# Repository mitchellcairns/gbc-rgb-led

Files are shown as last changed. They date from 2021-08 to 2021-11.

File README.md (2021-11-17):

# gbc-rgb-led 
**DEPRECIATED - SEE https://github.com/mitchellcairns/gbc-rgb-led-2.0**

__________________________
Gameboy Color RGB board for lighting up buttons with on-board controls.

This mod has the following modes and features
- Rainbow fade mode
- User preset mode to change hue and saturation of each button individually
- LEDs for all buttons and the power LED
- Brightness control
- All settings save to EEPROM so your preference is remembered through power cycles/battery changes

Controls in idle mode
- Press select three times and hold on the final press = Enter config mode
- While in config mode, use dpad left and right to change color mode
- After selecting your color mode, press select three times and hold on final press = Enter color edit mode

If you are in 'User preset mode'
- Use dpad left and right to select which LED you'd like to modify
- press select twice and hold to enter hue selection mode
- use dpad left and right to select your hue
- press twice and hold to enter saturation selection mode
- use dpad left and right to select your saturation
- press select twice and hold to go back to button selection
- press select three times and hold to enter brightness selection mode

If you are in 'Rainbow color mode'
- Use dpad left and right to change the rainbow fade speed
- press three times and hold to enter brightness selection mode

If you are in 'Solid color mode'
- Use dpad left and right to change the color hue
- press select twice and hold to enter saturation selection mode
- use dpad left and right to select your saturation
- press select three times and hold to enter brightness selection mode

If you are in 'Brightness selection mode'
- Use dpad left and right to choose your brightness
- press select three times and hold to save all settings and return to 'Idle' mode

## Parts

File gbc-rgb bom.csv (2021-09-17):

Item Link | Qty | Item Name | Board Label
https://www.aliexpress.com/item/32878302621.html?spm=a2g0s.9042311.0.0.12ab4c4d19utiV | 9 | WS2812B-2020 (5mA variant) | L1-L9
https://www.aliexpress.com/item/1005003126067624.html | 1 | ATTINY85-20SU SOP-8 | U1
https://www.aliexpress.com/item/1005001436923851.html | 1 | 330 ohm 0603 SMT resistor | R1
https://www.digikey.com/en/products/detail/yageo/RE0603FRE071KL/5923313 | 1 | 1k ohm 0603 SMT resistor | R2

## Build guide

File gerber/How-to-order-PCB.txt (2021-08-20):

How to Order PCB

Please refer to:
https://docs.easyeda.com/en/PCB/Order-PCB

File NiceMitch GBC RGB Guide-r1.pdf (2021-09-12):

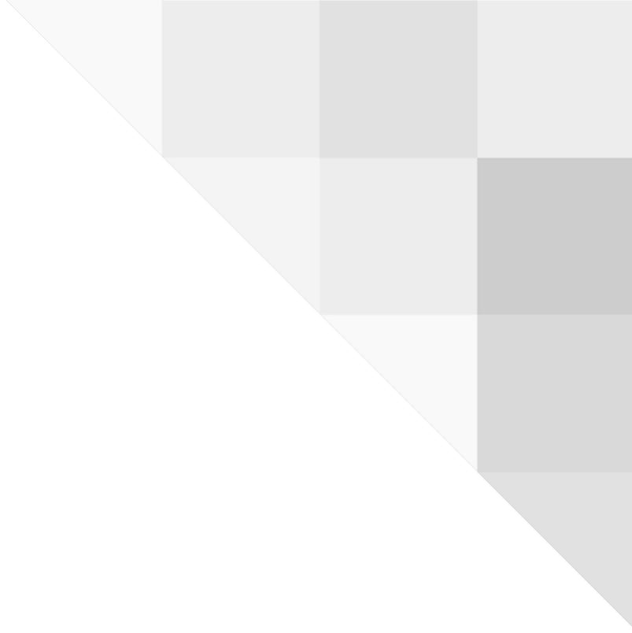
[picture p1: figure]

# NiceMitch’s GBC RGB Guide

# Product Guide

Last Updated September 12th, 2021

# 1. Product Controls Overview

There are two types of inputs-- presses and holds.

A press is performed by pressing the Select button, or D-Pad Left or Right.

A hold is performed by pressing the Select button any number of times, then holding the final press. Keep these directions in mind when reading the guide below and you will be successful in configuring/controlling your LEDs.

# 2. Color Modes

### A. Preset mode -- Modifiable color preset B. Solid color mode -- A mode to simply display one color C. Rainbow fade mode -- A mode that fades between all colors continuously

# 3. Device Modes and Controls

## A. Default mode

Upon receiving your kit, the device will be in ‘default’ mode. You can enter configuration mode by pressing select 3 times and holding. You will know you’ve entered configuration mode when you see the lights flash teal twice.

## B. Configuration mode

When you enter configuration mode, you will first enter the color mode select phase. Press Dpad Left and Right to cycle between each of the 3 color modes.

In advanced configuration mode, press select three times and hold to enter edit mode; this is the second step which will allow you to customize your chosen color mode. You will know you are entering edit mode when you see the lights flash pink twice.

## C. Edit mode

Edit mode will change depending on the color mode you are in.

1. When in preset mode:
a. Dpad left and right are pressed to select which button you would like to modify.
b. Press select twice and hold to enter hue selection for the chosen button. Dpad left and right can be used to adjust the color hue.
c. Press select twice and hold again to enter saturation selection for the chosen button. Dpad left and right can be used to adjust the color saturation.
d. Press select twice and hold again to go back to button selection.
2. When in solid color mode:
a. Hue selection mode is the default. Press select twice and hold to enter saturation selection mode. Use the dpad to change the hue.
b. Press select twice and hold to go back to hue selection mode. Use the dpad to change saturations.
3. When in rainbow mode:
a. Dpad left and right adjusts the color fade speed.
4. To save and continue to brightness configuration mode, press select three times and hold. You will know you’ve entered brightness mode when the leds flash yellow twice.

## D. Brightness configuration mode

This mode simply lets you change the brightness. This is the final setting that needs to be modified before all settings can be saved to the onboard storage.

1. Adjust brightness with dpad left and right.
2. Save all settings and reboot -- press select three times and hold. You will know you have saved all settings when you see the lights flash white twice.

# 4. Flex PCB Install

a. Disassemble your Gameboy Color console. See this guide on iFixit (https://www.ifixit.com/Teardown/Game+Boy+Color+Teardown/73017) for details.
b. Remove the power LED by heating the two legs from the rear side of the board with a soldering iron. Adding fresh solder to these two points can help. Solder wick or a solder sucker can help.

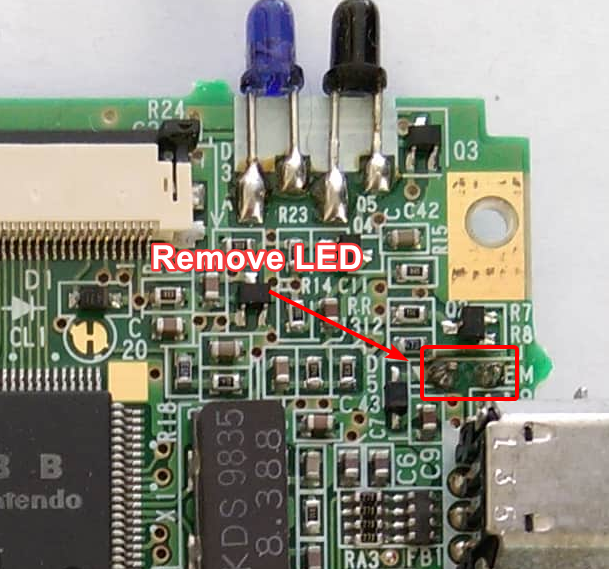
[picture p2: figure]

c. Flip the Gameboy Color PCB over. Align the flex board on the main board as shown. You will solder each of the points circled in red. Be sure to check your

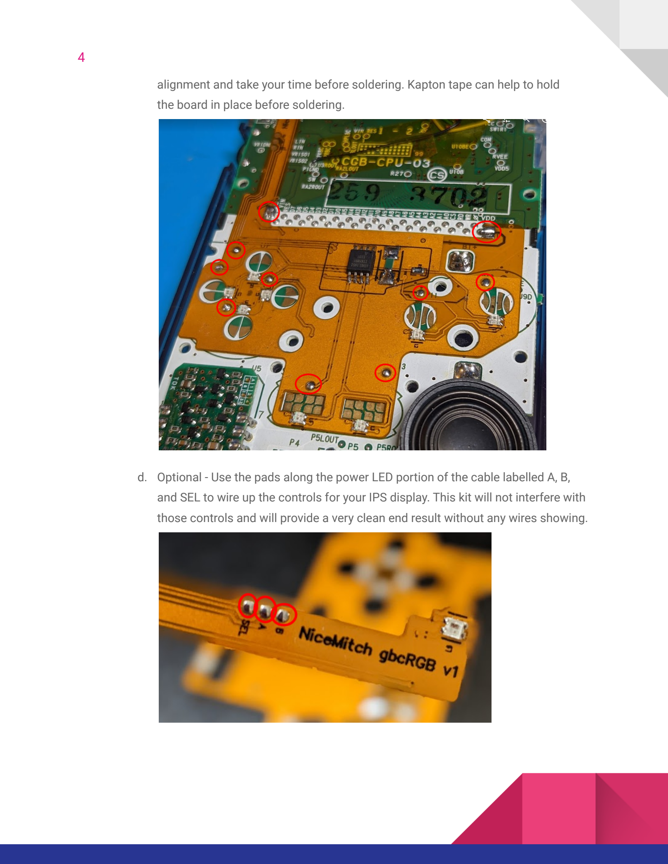
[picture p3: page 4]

alignment and take your time before soldering. Kapton tape can help to hold the board in place before soldering.

d. Optional - Use the pads along the power LED portion of the cable labelled A, B, and SEL to wire up the controls for your IPS display. This kit will not interfere with those controls and will provide a very clean end result without any wires showing.

e. Once you have ensured all connections are secured, you can reassemble and test. The lights should turn on immediately when powering up. An additional strip of kapton tape can be used to secure the long portion of the flex cable with the power LED. If you do have any issues, feel free to join my discord channel for additional support: https://discord.gg/jFxtr9mzCB

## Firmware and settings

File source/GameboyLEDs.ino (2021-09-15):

#include <FastLED.h>
#include <EEPROM.h>
#include "config.h"

#define LED_PIN 4

#define LED_COUNT 9

#define CHECK_COUNT 8 // How many times to poll buttons for averages
#define CHECK_SAVE 8

#define MAX_BRIGHTNESS 80
#define RCV 180

// PIN setup
// ----------------
const int selPIN = 0;
const int leftPIN = 2;
const int rightPIN = 1;
// ----------------
// ----------------

// Button states setup
#define NO_PRESS        0
#define RELEASED_PRESS  1
#define HELD_PRESS      2
// ----------------
// ----------------

// Dpad states setup
#define DPAD_LEFT       0
#define DPAD_RIGHT      1
#define DPAD_NEUTRAL    2
byte dpadPresses = 0;

// Release state setup
#define HELD_START      100
#define HELD_ONE        100
#define HELD_TWO        101
#define HELD_THREE      102
// ----------------
// ----------------

// Definitions for the different color modes
byte colorMode = 0;
#define COLORMODE_RAINBOW 0
#define COLORMODE_USER 1
#define COLORMODE_SOLID 2
// ----------------
// ----------------

int brightness = 20;

int selValue = HIGH;
int leftValue = HIGH;
int rightValue = HIGH;

bool leftPressed = false;
bool rightPressed = false;
byte selPressed = 0;
bool finishedHold = true;

byte timer = 0;
byte buttonTime = 250;
byte buttonPresses = 0;


bool colorDirty = true;
bool colorSet = false; // Set true to start a fade
bool colorInit = false; // Set true after changing and setting up your mode
float colorIncrement = 0; // Used to determine how to fade

byte colorStep = 15;
byte fadeTime = 50;
byte rainbowTime = 50;
#define COLOR_TIME    50
CHSV rainbowColor = CHSV(0,255,RCV);

CRGB leds[LED_COUNT] = { CRGB::Black, CRGB::Black, CRGB::Black, CRGB::Black, CRGB::Black, CRGB::Black, CRGB::Black, CRGB::Black, CRGB::Black};;
CRGB lastLeds[LED_COUNT];
CRGB nextLeds[LED_COUNT];
CRGB ledPreset[LED_COUNT] = { 0xff0505, 0xff8605, 0xfff700, 0x22ff00, 0x0022ff, 0x0022ff, 0x0022ff, 0x0022ff, 0xAE00ff};
CRGB editPresetLeds[LED_COUNT];

UserPreference upref;

void setup() {
  
  // put your setup code here, to run once:
  FastLED.addLeds<WS2812B, LED_PIN, RGB>(leds, LED_COUNT);
  FastLED.setBrightness(brightness);
  rainbowColor.value = RCV;

  pinMode(selPIN, INPUT_PULLUP);
  pinMode(leftPIN, INPUT_PULLUP);
  pinMode(rightPIN, INPUT_PULLUP);
  pinMode(3, OUTPUT);
  digitalWrite(3, LOW);

  delay(100);
  EEPROM.get(0, upref);
  delay(100);

  // Try to load upref data
  if (upref.saved == CHECK_SAVE) {
    brightness = upref.brightness;
    colorMode = upref.colorMode;
    rainbowTime = upref.rainbowTime;
    rainbowColor.hue = upref.hue;
    rainbowColor.saturation = upref.saturation;
    for (byte i = 0; i < LED_COUNT; i++) {
      ledPreset[i] = upref.ledPreset[i];
    }
  }

  FastLED.show();
  
}

void loop() {
  byte butt = buttonCounter();
  idle(butt);
}

// Functions to handle looking at the different button inputs

void smooth() { // Smooth read of values
  selValue = HIGH;
  rightValue = HIGH;
  leftValue = HIGH;

  for (byte i = 0; i < CHECK_COUNT; i++) {
    if (digitalRead(selPIN) == LOW) selValue = LOW;
    if (digitalRead(rightPIN) == LOW) rightValue = LOW;
    if (digitalRead(leftPIN) == LOW) leftValue = LOW;
  }
  FastLED.delay(1);

}

byte buttonCheck(bool timeOver) {
  smooth();

  dpadPresses = dpadCheck();

  if (selValue==LOW and !selPressed) {
    selPressed = true;
  }
  else if (selPressed and selValue==HIGH and finishedHold) {
    selPressed = false;
    return RELEASED_PRESS;
  }
  else if (!finishedHold and selValue==HIGH){
    selPressed = false;
    finishedHold = true;
  }
  
  if (selPressed and timeOver) {
    selPressed = false;
    finishedHold = false;
    return HELD_PRESS;
  }

  return NO_PRESS;
}

byte dpadCheck()  {
  
  if (!leftPressed and leftValue==LOW) {
    leftPressed = true;
  }
  else if (leftPressed and leftValue==HIGH) {
    leftPressed = false;
    return DPAD_LEFT;
  }

  if (!rightPressed and rightValue==LOW) {
    rightPressed = true;
  }
  else if (rightPressed and rightValue==HIGH) {
    rightPressed = false;
    return DPAD_RIGHT;
  }
  return DPAD_NEUTRAL; 
}

byte buttonCounter() {
  if (timer > 0 and timer < buttonTime) { // If we're in a time loop, do the following
    timer += 1;
  }

  byte btChk = 0;
  if (timer >= buttonTime) btChk = buttonCheck(true);
  else btChk = buttonCheck(false);
  
  if (btChk == RELEASED_PRESS) { // When a button is pressed what do we do?
    if (timer == 0 and buttonPresses == 0) { // If we haven't started a timer, lets add a button press and begin adding to the timer.
      timer += 1;
      buttonPresses = 1;
    }
    else if (timer < buttonTime) { // If we are still in the allotted timeframe, add another button press.
      buttonPresses += 1;
    }
  }
  
  if (timer >= buttonTime) { // What do we do if the timer is full? We reset the timer, return the button press count and reset that.
    byte toReturn = buttonPresses;
    if (btChk == HELD_PRESS){
      toReturn += HELD_START;
    }
    buttonPresses = 0;
    timer = 0;
    return toReturn;
  }

  // Default return 0
  return 0;
}
// ----------------
// ----------------

// Definitions for device modes
byte configMode = 0;
#define DEFAULT_MODE      0
#define CONFIG_MODE       1
#define EDIT_MODE         2
#define BRIGHTNESS_MODE   3
// ----------------
// ----------------

// Definitions for dit modes
byte editMode = 0;
#define EDIT_CHOOSE       0
#define EDIT_HUE          1
#define EDIT_SATURATION   2

byte presetEdit = false;

// Definitions for different button functions
#define SATURATION_UP     0 //
#define SATURATION_DOWN   1 //
#define HUE_UP            2 //
#define HUE_DOWN          3 //
#define COLOR_MODE_UP     4 //
#define COLOR_MODE_DWN    5 //
#define RAINBOW_UP        6 //
#define RAINBOW_DOWN      7 //
#define BRIGHT_UP         8 //
#define BRIGHT_DOWN       9 //
#define SAVE_ALL          10
#define ENABLE_CONFIG     11 
#define NEXT_BUTTON       12
#define PREV_BUTTON       13
#define ENABLE_EDIT       14
#define ENABLE_BRIGHTNESS 15
#define RESET_CALIBRATION 16
#define ENABLE_HUESELECT  17
#define ENABLE_SATSELECT  18

// ----------------
// ----------------

// Definitions for modifying user preset
byte buttonEditing = 0;
#define A_EDIT            0
#define B_EDIT            1
#define DPAD_EDIT         2
#define SEL_EDIT          3
#define START_EDIT        4
#define POWER_EDIT        5

void buttonFunction(byte in)  {
  if (in == COLOR_MODE_UP) {
    if (colorMode + 1 > 2) colorMode = 0;
    else colorMode += 1;
    if (colorMode == COLORMODE_SOLID)
    {
      if (upref.saved == CHECK_SAVE) {
        rainbowColor.hue = upref.hue;
        rainbowColor.saturation = upref.saturation;
      }
      else rainbowColor = CHSV(0,255,RCV);
    }
    resetColor(false);
  }
  else if (in == COLOR_MODE_DWN) {
    if (colorMode - 1 < 0) colorMode = 2;
    else colorMode -= 1;
    if (colorMode == COLORMODE_SOLID)
    {
      if (upref.saved == CHECK_SAVE) {
        rainbowColor.hue = upref.hue;
        rainbowColor.saturation = upref.saturation;
      }
      else rainbowColor = CHSV(0,255,RCV);
    }
    resetColor(false);
  }
  else if (in == SATURATION_UP) {
    if (rainbowColor.saturation + 20 >= 255)
    rainbowColor.saturation = 255;
    else rainbowColor.saturation += 20;
    if (configMode == EDIT_MODE and colorMode == COLORMODE_USER)
      setButtonGroup(buttonEditing, false);
    resetColor(colorMode == COLORMODE_RAINBOW);
  }
  else if (in == SATURATION_DOWN) {
    if (rainbowColor.saturation - 20 <= 0)
    rainbowColor.saturation = 0;
    else rainbowColor.saturation -= 20;
    if (configMode == EDIT_MODE and colorMode == COLORMODE_USER)
      setButtonGroup(buttonEditing, false);
    resetColor(colorMode == COLORMODE_RAINBOW);
  }
  else if (in == BRIGHT_UP) {
    if (brightness + 10 >= MAX_BRIGHTNESS)
    brightness = MAX_BRIGHTNESS;
    else brightness += 10;
    FastLED.setBrightness(brightness);
    FastLED.show();
  }
  else if (in == BRIGHT_DOWN) {
    if (brightness - 10 <= 0)
    brightness = 0;
    else brightness -= 10;
    FastLED.setBrightness(brightness);
    FastLED.show();
  }
  else if (in == NEXT_BUTTON) {
    if (buttonEditing + 1 > 5) buttonEditing = 0;
    else buttonEditing += 1;
    rainbowColor = CHSV(0,255,RCV);
    setButtonGroup(buttonEditing, true);
  }
  else if (in == PREV_BUTTON) {
    if (buttonEditing - 1 < 0) buttonEditing = 5;
    else buttonEditing -= 1; 
    rainbowColor = CHSV(0,255,RCV);
    setButtonGroup(buttonEditing, true);
  }
  else if (in == HUE_UP) {
    rainbowColor.hue += 15;
    if (rainbowColor.hue > 255) rainbowColor.hue = 0;
    if (configMode == EDIT_MODE and colorMode == COLORMODE_USER)
      setButtonGroup(buttonEditing, false);
    resetColor(colorMode == COLORMODE_RAINBOW);
  }
  else if (in == HUE_DOWN) {
    rainbowColor.hue -= 15;
    if (rainbowColor.hue < 0) rainbowColor.hue = 255;
    if (configMode == EDIT_MODE and colorMode == COLORMODE_USER)
      setButtonGroup(buttonEditing, false);
    resetColor(colorMode == COLORMODE_RAINBOW);
  }
  else if (in == RAINBOW_UP) {
    rainbowTime += 10;
    if (rainbowTime > 60) rainbowTime = 60;
  }
  else if (in == RAINBOW_DOWN) {
    rainbowTime -= 10;
    if (rainbowTime <= 10) rainbowTime = 10;
  }
  else if (in == ENABLE_CONFIG) {
    configMode = CONFIG_MODE;
    switchIndicator(CRGB::Teal);
    resetColor(false);
  }
  else if (in == ENABLE_EDIT) {
    configMode = EDIT_MODE;
    if (colorMode == COLORMODE_USER) {
      rainbowColor = CHSV(0,255,RCV); // Set to red
      editMode = EDIT_CHOOSE;
      setButtonGroup(buttonEditing, true);
    }
    else if (colorMode == COLORMODE_SOLID) {
      editMode = EDIT_HUE;
    }
    switchIndicator(CRGB::Pink);
    resetColor(false);
  }
  else if (in == ENABLE_BRIGHTNESS) {
    configMode = BRIGHTNESS_MODE;
    switchIndicator(CRGB::Yellow);
    resetColor(false);
  }
  else if (in == ENABLE_HUESELECT) {
    editMode = EDIT_HUE;
    if (colorMode == COLORMODE_USER)
    {
      setButtonGroup(buttonEditing, false);
    }
    switchIndicator(CRGB::Pink);
    resetColor(false);
  }
  else if (in == ENABLE_SATSELECT) {
    editMode = EDIT_SATURATION;
    if (colorMode == COLORMODE_USER)
    {
      setButtonGroup(buttonEditing, false);
    }
    switchIndicator(CRGB::Red);
    resetColor(false);
  }
  else if (in == SAVE_ALL)  {
    upref.saved = CHECK_SAVE;
    upref.brightness = brightness;
    upref.colorMode = colorMode;
    upref.rainbowTime = rainbowTime;
    upref.hue = rainbowColor.hue;
    upref.saturation = rainbowColor.saturation;
    for (byte i = 0; i < LED_COUNT; i++) {
      upref.ledPreset[i] = ledPreset[i];
    }
    
    EEPROM.put(0, upref);
    delay(100);
    configMode = DEFAULT_MODE;
    switchIndicator(CRGB::White);
    resetColor(false);
  }

}

void switchIndicator(CRGB col) {
  FastLED.setBrightness(25);
  for (byte i = 0; i < 2; i++)
  {
    fill_solid(leds, LED_COUNT, col);
    FastLED.show();
    delay(500);
    FastLED.clear();
    FastLED.show();
    delay(500);
  }
  FastLED.setBrightness(brightness);
}

void setNextColors(CRGB colors[LED_COUNT]) {
  for (byte i = 0; i < LED_COUNT; i++) {
    lastLeds[i] = leds[i];
    nextLeds[i] = colors[i];
  }
  resetColor(false);
}

void setNextColor(CRGB color) {
  for (byte i = 0; i < LED_COUNT; i++) {
    lastLeds[i] = leds[i];
    nextLeds[i] = color;
  }
  resetColor(colorMode==COLORMODE_RAINBOW);
}

// Button groups
// 0,1 are A button
// 2 are B button
// 3 reserved for Power indicator for debug

void setButtonGroup(byte buttonGroup, bool loadDefault) {
    
  for (byte i = 0; i < LED_COUNT; i++) {
    editPresetLeds[i] = CHSV(0,25,25);
  }
  
  if (buttonGroup == A_EDIT) {
    if (loadDefault) {
      editPresetLeds[0] = ledPreset[0];
    }
    else {
      editPresetLeds[0] = rainbowColor;
      ledPreset[0] = rainbowColor;
    }
  }
  else if (buttonGroup == B_EDIT) {
    if (loadDefault) {
      editPresetLeds[1] = ledPreset[1];
    }
    else {
      editPresetLeds[1] = rainbowColor;
      ledPreset[1] = rainbowColor;
    }
  }
  else if (buttonGroup == DPAD_EDIT) {
    if (loadDefault) {
      editPresetLeds[4] = ledPreset[4];
      editPresetLeds[5] = ledPreset[5];
      editPresetLeds[6] = ledPreset[6];
      editPresetLeds[7] = ledPreset[7];
    }
    else {
      editPresetLeds[4] = rainbowColor;
      ledPreset[4] = rainbowColor;
      editPresetLeds[5] = rainbowColor;
      ledPreset[5] = rainbowColor;
      editPresetLeds[6] = rainbowColor;
      ledPreset[6] = rainbowColor;
      editPresetLeds[7] = rainbowColor;
      ledPreset[7] = rainbowColor;
    }
  }
  else if (buttonGroup == START_EDIT) {
    if (loadDefault) {
      editPresetLeds[2] = ledPreset[2];
    }
    else {
      editPresetLeds[2] = rainbowColor;
      ledPreset[2] = rainbowColor;
    }
  }
  else if (buttonGroup == SEL_EDIT) {
    if (loadDefault) {
      editPresetLeds[3] = ledPreset[3];
    }
    else {
      editPresetLeds[3] = rainbowColor;
      ledPreset[3] = rainbowColor;
    }
  }
  else if (buttonGroup == POWER_EDIT) {
    if (loadDefault) {
      editPresetLeds[8] = ledPreset[8];
    }
    else {
      editPresetLeds[8] = rainbowColor;
      ledPreset[8] = rainbowColor;
    }
  }
  resetColor(false);
}

void colorTick(float changeTime) { // Handle fading between colors for transition purposes
  if (colorDirty and !colorSet) {

    colorIncrement += (255 / changeTime);
    byte inc = (byte) colorIncrement;

    for (byte i = 0; i < LED_COUNT; i++) { // Set the next color on all LEDs blended
      leds[i] = blend(lastLeds[i], nextLeds[i], inc);
    }

    if (inc >= 255) { // If the fade is complete, reset the increment and set as not dirty!
      for (byte i = 0; i < LED_COUNT; i++) {
        leds[i] = nextLeds[i]; // Set all colors to their final form
      }
      colorIncrement = 0;
      colorDirty = false; // Unmark that the color is dirty
      colorSet = true; // Mark that the color has been 'set'.
    }

  }
  FastLED.show(); // Send update to LEDs
}

void resetColor(bool init) {
  FastLED.setBrightness(brightness);
  colorDirty = true;
  colorSet = false;
  colorInit = init;
}

void idle(byte pressCount) {
  // COLOR RUNTIME
  if (!colorSet and colorDirty and !colorInit) {
    fadeTime = COLOR_TIME;
    if (colorMode == COLORMODE_USER) {
      if (configMode == EDIT_MODE)
      {
        setNextColors(editPresetLeds);
      }
      else setNextColors(ledPreset);
      
    }
    else if (colorMode == COLORMODE_SOLID) {
      setNextColor(rainbowColor);
    }
    else if (colorMode == COLORMODE_RAINBOW and !colorInit) {
      fadeTime = rainbowTime;
      rainbowColor = CHSV(0,255,RCV);
      setNextColor(rainbowColor);
      colorInit = true;
    }
  }
  else if (colorSet and (colorMode == COLORMODE_RAINBOW) and !colorDirty and colorInit) { // Special rule for rainbow mode
    fadeTime = rainbowTime;
    buttonFunction(HUE_UP);
    setNextColor(rainbowColor);
    colorInit = true;
  }

  colorTick(fadeTime);

  // USER INTERFACE
  if (configMode == DEFAULT_MODE) {
    if (pressCount == HELD_THREE) buttonFunction(ENABLE_CONFIG);
  }
  else if (configMode == CONFIG_MODE) {
    if (dpadPresses == DPAD_LEFT) buttonFunction(COLOR_MODE_DWN);
    else if (dpadPresses == DPAD_RIGHT) buttonFunction(COLOR_MODE_UP);
    else if (pressCount == HELD_THREE) buttonFunction(ENABLE_EDIT);
  }
  else if (configMode == BRIGHTNESS_MODE) {
    if (dpadPresses == DPAD_LEFT) buttonFunction(BRIGHT_DOWN);
    else if (dpadPresses == DPAD_RIGHT) buttonFunction(BRIGHT_UP);
    else if (pressCount == HELD_THREE) buttonFunction(SAVE_ALL);
  }
  else if (configMode == EDIT_MODE) {

    // user preset mode edit options
    if (colorMode == COLORMODE_USER) {
      if (editMode == EDIT_CHOOSE) {
        if (pressCount == HELD_TWO) buttonFunction(ENABLE_HUESELECT);
        else if (dpadPresses == DPAD_LEFT) buttonFunction(PREV_BUTTON);
        else if (dpadPresses == DPAD_RIGHT) buttonFunction(NEXT_BUTTON);
      }
      else if (editMode == EDIT_HUE) {
        if (dpadPresses == DPAD_LEFT) buttonFunction(HUE_DOWN);
        else if (dpadPresses == DPAD_RIGHT) buttonFunction(HUE_UP);
        else if (pressCount == HELD_TWO) buttonFunction(ENABLE_SATSELECT);
      }
      else if (editMode == EDIT_SATURATION) {
        if (dpadPresses == DPAD_LEFT) buttonFunction(SATURATION_DOWN);
        else if (dpadPresses == DPAD_RIGHT) buttonFunction(SATURATION_UP);
        else if (pressCount == HELD_TWO) buttonFunction(ENABLE_EDIT);
      }
    } 
    // ----------------
    // ----------------

    // solid color edit mode
    else if (colorMode == COLORMODE_SOLID) {
      if (editMode == EDIT_HUE) {
        if (dpadPresses == DPAD_LEFT) buttonFunction(HUE_DOWN);
        else if (dpadPresses == DPAD_RIGHT) buttonFunction(HUE_UP);
        else if (pressCount == HELD_TWO) buttonFunction(ENABLE_SATSELECT);
      }
      else if (editMode == EDIT_SATURATION) {
        if (dpadPresses == DPAD_LEFT) buttonFunction(SATURATION_DOWN);
        else if (dpadPresses == DPAD_RIGHT) buttonFunction(SATURATION_UP);
        else if (pressCount == HELD_TWO) buttonFunction(ENABLE_HUESELECT);
      }
    }
    // ----------------
    // ----------------

    // rainbow color edit mode
    else if (colorMode == COLORMODE_RAINBOW) {
      if (dpadPresses == DPAD_LEFT) buttonFunction(RAINBOW_DOWN);
      else if (dpadPresses == DPAD_RIGHT) buttonFunction(RAINBOW_UP);
    }

    if (pressCount == HELD_THREE) buttonFunction(ENABLE_BRIGHTNESS);
  }

}

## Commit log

2021-08-28 updated bom to change out capacitor for resistor
    [gbc-rgb bom.csv]
2021-09-12 Fix LED Count and more
    This update fixes the LED count in the user preset saving/loading properly.
    This update also fixes the button editing to work with all buttons.
    [GameboyLEDs.ino]
2021-09-15 Fixed bug with power LED color not saving/loading
    [GameboyLEDs.ino]
2021-09-17 Updated board to 1.1
    [Gerber_BoardOutline.GKO, Gerber_BottomLayer.GBL, Gerber_BottomSolderMaskLayer.GBS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]
